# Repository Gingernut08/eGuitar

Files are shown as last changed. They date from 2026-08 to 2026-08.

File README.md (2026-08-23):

Fully custom designed electric guitar, main body and fretboard made from fdm printed petg, neck made from planed European oak with a steel tensioning rod. This guitar has a scale of 648mm and has 24 frets, a 5 way selector switch allows for easy changing between the bridge, mid and neck pickups in combinations: n, mn, m, mb, b (n = neck, m = mid, b = bridge) with 2 tone and 1 volume control. Output is unbalanced 1/4" jack which is located below the mount for the strap on the back of the guitar. Access to the electrical components is granted through a removeable back plate held in place by 9 m2 bolts.

The guitar is put together with locating pins on 3d prints, as well as dovetail connectors which lock them in place, the neck is connected using multiple bolts as well as locating pins, pickups are screwed into place, as well as other elecronics.

**CAD**

Full cad assembly



Pickup



Neck



Fretboard



Back hollow



Wiring



**[BOM:](https://github.com/Gingernut08/eGuitar/blob/main/bom.csv)**

| Item | Amount | Price ($) | Link |
| --- | -----: | ---: | --- |
| Tuning pegs | 6 | 6.63 | [AliExpress](https://www.aliexpress.com/item/1005009623082250.html) |
| Strap button | 2 | 1.65 | [AliExpress](https://www.aliexpress.com/item/1005012385459057.html) |
| Fret wires | 24 | 3.09 | [AliExpress](https://www.aliexpress.com/item/1005006474565113.html) |
| Potentiometers | 3 | 7.13 | [AliExpress](https://www.aliexpress.com/item/1005010542228242.html) |
| Tensioning rod | 1 | 7.92 | [AliExpress](https://www.aliexpress.com/item/32911016790.html) |
| 5-way switch | 1 | 3.56 | [AliExpress](https://www.aliexpress.com/item/1005004102817118.html) |
| Pickup magnets | 24 | 25.79 | [AliExpress](https://www.aliexpress.com/item/1005005671763879.html) |
| Pickup wire | 500g | 37.04 | [AliExpress](https://www.aliexpress.com/item/1005010157248758.html) |
| 25x57x1000mm oak | | 14.53 | [britishhardwoods](https://www.britishhardwoods.co.uk/planed-all-round-european-oak-timber.html) |
| 3D Printing | 1kg | 30.00 | — |
| **Total** | | **$137.34** | |

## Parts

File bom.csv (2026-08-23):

Item | Amount | Price ($) | Link
Tuning pegs | 6 | 6.63 | https://www.aliexpress.com/item/1005009623082250.html
Strap button | 2 | 1.65 | https://www.aliexpress.com/item/1005012385459057.html
Fret wires | 24 | 3.09 | https://www.aliexpress.com/item/1005006474565113.html
Potentiometers | 3 | 7.13 | https://www.aliexpress.com/item/1005010542228242.html
Tensioning rod | 1 | 7.92 | https://www.aliexpress.com/item/32911016790.html
5-way switch | 1 | 3.56 | https://www.aliexpress.com/item/1005004102817118.html
Pickup magnets | 24 | 25.79 | https://www.aliexpress.com/item/1005005671763879.html
Pickup wire | 500g | 37.04 | https://www.aliexpress.com/item/1005010157248758.html
25x57x1000mm oak |  | 14.53 | https://www.britishhardwoods.co.uk/planed-all-round-european-oak-timber.html
3D Printing | 1kg | 30.0
Total |  | 137.34

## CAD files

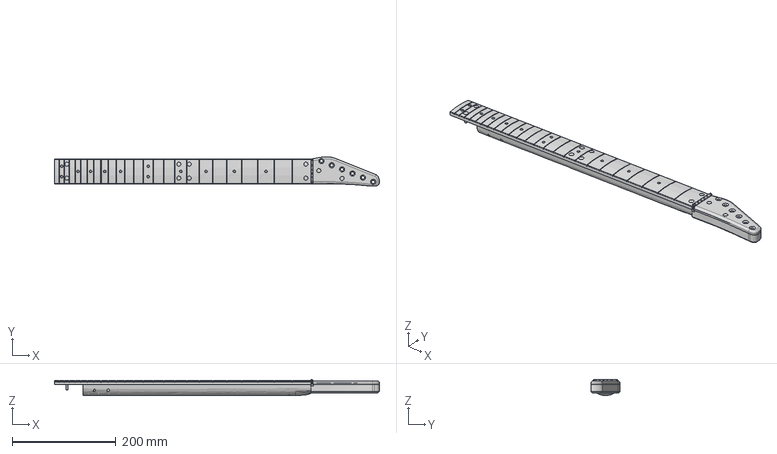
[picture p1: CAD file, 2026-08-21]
cad/neck_assembly.step
627.1 x 56.8 x 30.9 mm
neck
fret_board

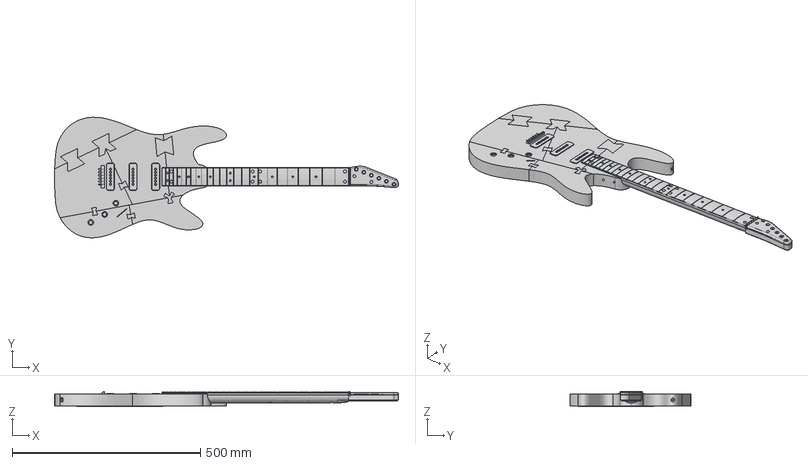
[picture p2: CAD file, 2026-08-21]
cad/main.step
913.1 x 320.1 x 41.0 mm
pickup_bobin x 3
neck
fret_board

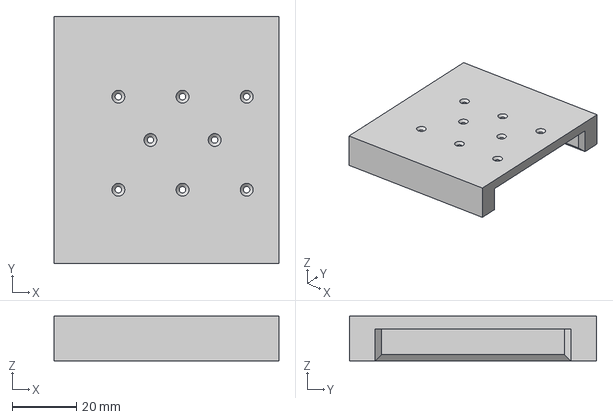
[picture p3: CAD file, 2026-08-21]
cad/jigs/neck_hole_template.step
70.0 x 77.0 x 14.0 mm

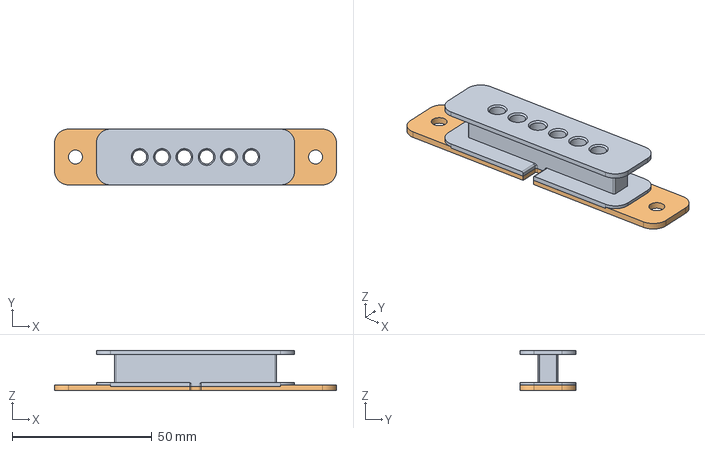
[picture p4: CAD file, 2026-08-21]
cad/pickup_bobin.step
101.0 x 20.0 x 14.5 mm

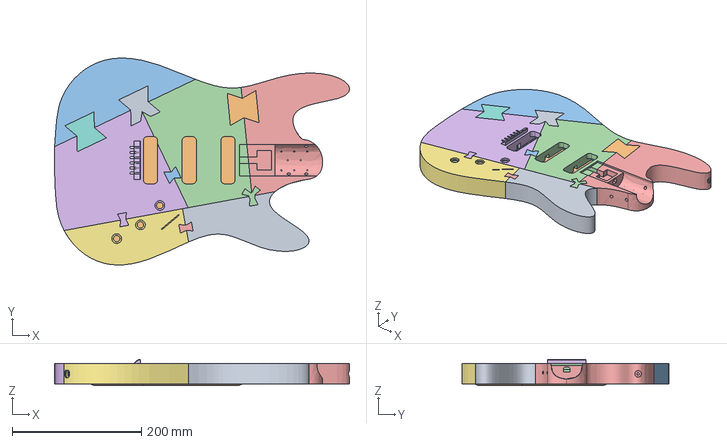
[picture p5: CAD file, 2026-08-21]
cad/body.step
456.4 x 320.2 x 40.2 mm

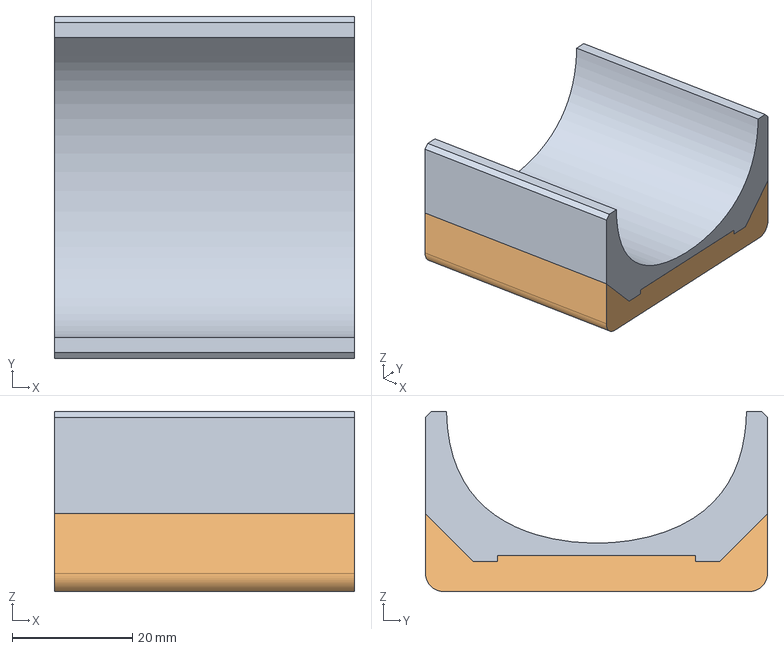
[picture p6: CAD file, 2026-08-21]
cad/jigs/neck_template.step
50.0 x 57.0 x 30.0 mm

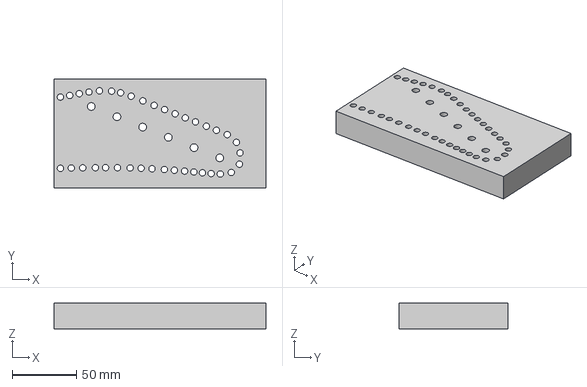
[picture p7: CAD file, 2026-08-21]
cad/jigs/headstock_guide.step
165.0 x 85.0 x 20.0 mm

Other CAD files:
cad/main.f3z

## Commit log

2026-08-21 Create bom.csv with item details
    Added a bill of materials (BOM) with item details including amounts, prices, and links.
    [bom.csv]
2026-08-21 Add headstock_guide.step file
    [headstock_guide.step]
2026-08-23 Revise BOM with new items and total price
    Updated the Bill of Materials (BOM) to include additional items and updated prices.
2026-08-23 Enhance README with CAD assembly images and BOM
    Added images and details for CAD assembly and BOM.
2026-08-23 Revise bom.csv to improve formatting and add items
    Updated BOM format and added new items.
    [bom.csv]
2026-08-23 Fix spelling error in README.md
    Corrected spelling of 'assembely' to 'assembly' in README.
2026-08-23 Enhance README with assembly details
    Added details about the assembly and connection methods used in the guitar design.
